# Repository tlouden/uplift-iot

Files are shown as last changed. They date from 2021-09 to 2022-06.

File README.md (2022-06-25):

# UPLIFT-IoT
Connecting an [UPLIFT](https://www.upliftdesk.com/) desk to Home Assistant using an ESP32 with ESP Home for Home Assistant.

## Disclaimer
This is an adversarial interop against a hardware interface. Any changes from the manufacturer could invalidate or even make this dangerous. Validate assumptions on your own system and proceed with caution. 

## Usage
The UART driver for ESP Home should work without modification. Everything else will need to be customized to your setup using the provided examples.

## ESP Home
An ESP32 is used with [ESP Home](https://esphome.io/). The specific board is a esp32doit-devkit-v1.
### esphome/uplift_uart.h
Custom UART driver that interprets the data from the UPLift desk unit.
### uplift-iot.yaml
An example definition for the device in ESPHome. Will need to be customized to be used.

## Home Assistant
Data is consumed by [Home Assistant](https://www.home-assistant.io/).
### homeassistant/automation.yaml 
An example automation which will need to be cusomized to be used.

## PCB / Board
[KiCAD](https://www.kicad.org/) files for a PCB are included for anyone that would like to produce their own. Here is the schematic if you'd like to breadboard it.
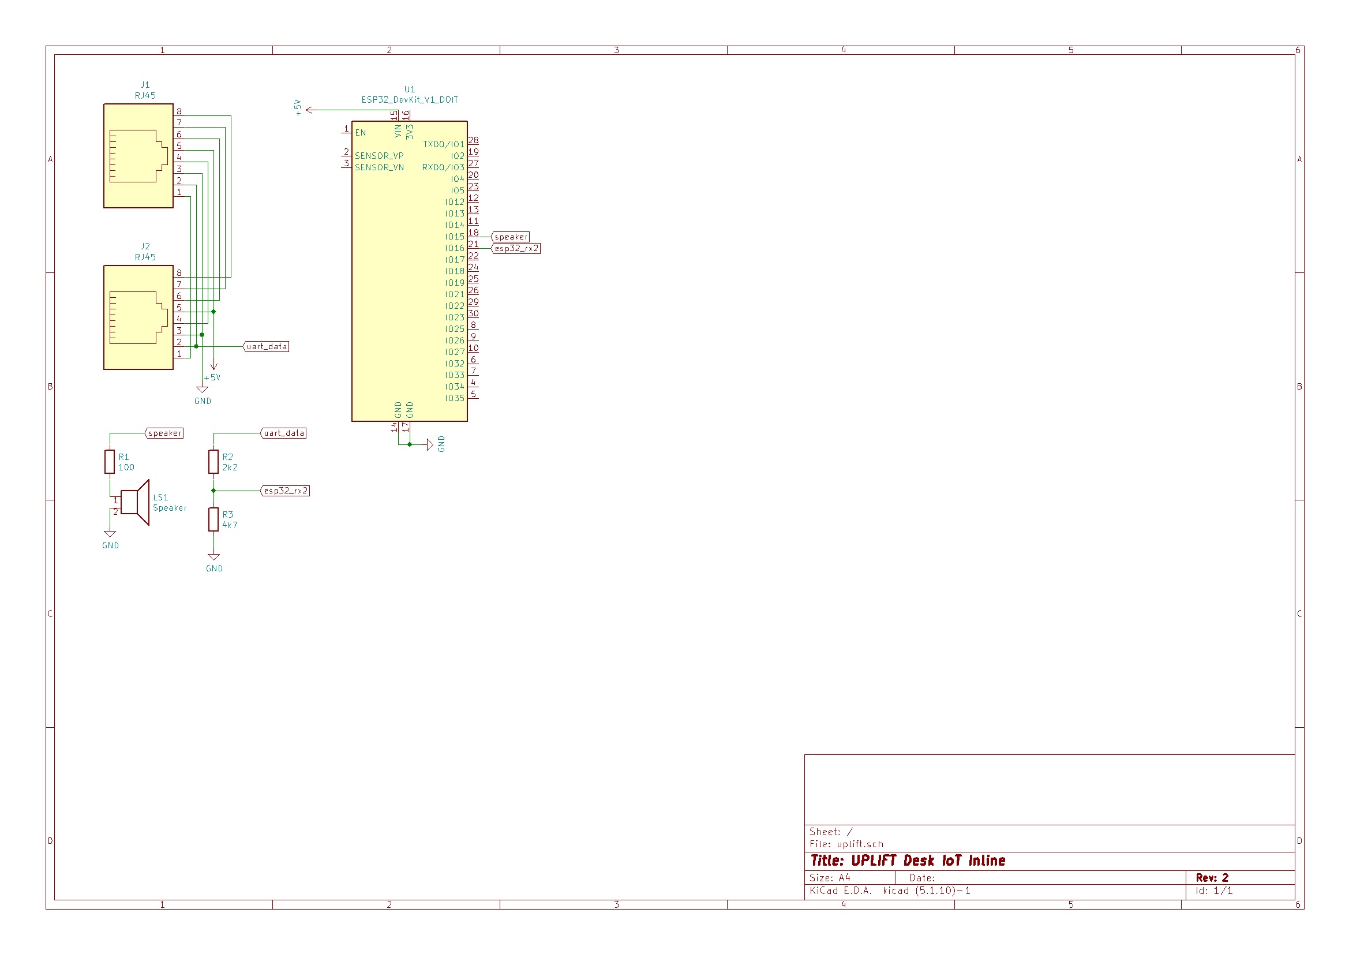
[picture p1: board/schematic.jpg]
schematic


## Enclosure
[OpenSCAD](https://openscad.org/) files for an enclosure are included for 3D printing. The default values are good even if you use a header to connect the ESP to the board. Use M3x4mm screws to attach the PCB. The lid will snap fit. The [BOSL2 library](https://github.com/revarbat/BOSL2) is used and included along with it's license file.

## Details
### UPLIFT Wiring
On My UPLIFT Desk, the keypad communicates with the motor box via an ethernet cable. A logic analyser shows that the second wire has a digital signal at 9600 baud. The third wire is ground, and the fifth is a 5v supply. All the others get pulled low by the keypad when buttons are pressed.
### Signal Analysis
I don't want remote control of the motors, so my analysis is focused exlusively on the serial data on line 2. The data only sends few a short period after the desk height changes, then goes dead. This isn't a problem, but is good to know when doing analysis. Starting with defaults for parity, stop bits, and data length produced the data sequence 1, 1, [0,1], [0-255] repeating. The format is big endian, so the first integer is always 257 and the second is the real data. It is sending the height in tenths of an inch, so 296 is 29.6".
### UART Driver
A simple approach is used for such a simple use case. We look for the expected 1,1 data sequence and then process the next two bytes. It is possible to get out of sequence when the desk is higher than 25.5" so if the first byte is not a 0 or 1, the logic resets to avoid non-sensical readings like 1000". This allows up to 51.1" to be expressed, and my desk only goes up to 50.8".

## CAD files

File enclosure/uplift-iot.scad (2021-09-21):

include <BOSL2/std.scad>
include <BOSL2/rounding.scad>
include <Libraries/calibration.scad>

/* [Rendering Selection] */
Part_To_Render="none"; // [none, full_assembly, bottom, top]

/* [General] */
//width of pcb (x-axis)
pcb_width=52.1;
//length of pcb (y-axis)
pcb_length=58.4;
//distance from inside wall of enclosure to edge of pcb
pcb_right_offset=2.0;
//distance from inside wall of enclosure to edge of pcb
pcb_left_offset=2.0;
//distance from inside wall of enclosure to edge of pcb
pcb_bottom_offset=2.0;
//distance from inside wall of enclosure to edge of pcb
pcb_top_offset=2.0;
//diameter of pcb mounting screws hole
pcb_mounting_screw_hole_diameter=2.5;
//height of pcb standoffs
standoff_height=3.0;
//standoff offset from edge of pcb to center of standoff (assumes symetric holes)
standoff_offset_x=5.0;
//standoff offset from edge of pcb to center of standoff (assumes symetric holes)
standoff_offset_y=3.8;
//distance from bottom of pcb to bottom of rj45 connector hole
rj45_pcb_to_bottom=1.6;
//height of rj45 connector hole (this determines the height of the enclosure)
rj45_height=17.4;
//distance from edge of pcb to edge of rj45 connector hole
rj45_left_offset=10.7;
//width of rj45 connector hole
rj45_width=15.4;
//distance between top of rj45 connector and bottom of lid
rj54_top_to_lid_bottom=5.7;
//width of vent slots
vent_size=2.5;
//margin from edge of lid to edge of venting
vent_free_margin=10.0;

/* [Adjustments] */
min_wall_size=2.0;
snap_fit_size=1.0;

/* [Hidden] */
$debug=false;
$overlap=0.001;
$fn=60;

//Calculated
$slop_tight=$slop*slop_tight_multiple;
$slop_tight_metal_round=$slop*slop_tight_metal_round_multiple;
$slop_tight_metal_square=$slop*slop_tight_metal_square_multiple;
$slop_free=$slop*slop_free_multiple;
enclosure_wall_size=min_wall_size+snap_fit_size+$slop_free;
enclosure_inner_width=pcb_width+pcb_right_offset+pcb_left_offset;
enclosure_width=enclosure_inner_width+2*enclosure_wall_size;
enclosure_inner_length=pcb_length+pcb_bottom_offset+pcb_top_offset;
enclosure_length=enclosure_inner_length+2*enclosure_wall_size;
enclosure_bottom_inner_height=standoff_height+rj45_pcb_to_bottom+rj45_height;
enclosure_bottom_height=min_wall_size+enclosure_bottom_inner_height;
snapfit_cutout_width=snap_fit_size+$slop_free+$overlap;
standoff_diameter=pcb_mounting_screw_hole_diameter+2*min_wall_size;
snapfit_corner_size=4*snap_fit_size+min_wall_size;
vent_x=vent_free_margin;
vent_width=enclosure_width-2*vent_free_margin;
vent_count=floor((enclosure_length-2*vent_free_margin-vent_size)/(2*vent_size))+1;
vent_y_start=enclosure_length/2-(vent_count*2*vent_size-vent_size)/2;

/* DEBUGGING */
if ($debug==true) {
    echo(slop=$slop);
    echo(slop_free=$slop_free);
}

if (Part_To_Render=="full_assembly") render_assembled();
if (Part_To_Render=="bottom") bottom();
if (Part_To_Render=="top") top();


module render_assembled() {
    bottom();
    translate([0, 0, enclosure_bottom_height+2])
    top();
}

module bottom() {
    union() {
        difference() {
            //enclosing
            cuboid([enclosure_width, enclosure_length, enclosure_bottom_height], anchor=FRONT+LEFT+BOTTOM, rounding=min_wall_size, except_edges=[TOP]);
            //inside
            translate([enclosure_wall_size, enclosure_wall_size, min_wall_size])
            cuboid([enclosure_inner_width, enclosure_inner_length, enclosure_bottom_inner_height+$overlap], anchor=FRONT+LEFT+BOTTOM, rounding=min_wall_size, except_edges=[TOP]);
            //rj45 - bottom
            translate([rj45_left_offset+pcb_left_offset+enclosure_wall_size, -$overlap, enclosure_bottom_height-rj45_height])
            cube([rj45_width, enclosure_wall_size+2*$overlap, rj45_height+$overlap]);
            //rj45 - top
            translate([rj45_left_offset+pcb_left_offset+enclosure_wall_size, enclosure_length-enclosure_wall_size-$overlap, enclosure_bottom_height-rj45_height])
            cube([rj45_width, enclosure_wall_size+2*$overlap, rj45_height+$overlap]);
            //snapfit
            translate([enclosure_wall_size+min_wall_size, min_wall_size+$overlap, enclosure_bottom_height-enclosure_wall_size])
            snapfit_cutout();
            translate([enclosure_inner_width-snapfit_cutout_width-min_wall_size, min_wall_size+$overlap, enclosure_bottom_height-enclosure_wall_size])
            snapfit_cutout();
            translate([enclosure_wall_size+min_wall_size, enclosure_inner_length+enclosure_wall_size-$overlap, enclosure_bottom_height-enclosure_wall_size])
            snapfit_cutout();
            translate([enclosure_inner_width-snapfit_cutout_width-min_wall_size, enclosure_inner_length+enclosure_wall_size-$overlap, enclosure_bottom_height-enclosure_wall_size])
            snapfit_cutout();
        }
        //standoffs
        translate([standoff_offset_x+enclosure_wall_size+pcb_left_offset, standoff_offset_y+enclosure_wall_size+pcb_bottom_offset, min_wall_size])
        standoff();
        translate([enclosure_wall_size+enclosure_inner_width-(standoff_offset_x+pcb_left_offset), standoff_offset_y+enclosure_wall_size+pcb_bottom_offset, min_wall_size])
        standoff();
        translate([standoff_offset_x+enclosure_wall_size+pcb_left_offset, enclosure_wall_size+enclosure_inner_length-(standoff_offset_y+pcb_top_offset), min_wall_size])
        standoff();
        translate([enclosure_wall_size+enclosure_inner_width-(standoff_offset_x+pcb_left_offset), enclosure_wall_size+enclosure_inner_length-(standoff_offset_y+pcb_top_offset), min_wall_size])
        standoff();
    }
}

module top() {
    union() {
        //plate
        difference() {
            cuboid([enclosure_width, enclosure_length, min_wall_size], anchor=FRONT+LEFT+BOTTOM, rounding=min_wall_size, except_edges=[BOTTOM, TOP]);
            //ventilation
            for (i=[0:vent_count-1]) {
                translate([vent_x, vent_y_start+i*2*vent_size, -$overlap])
                cuboid([vent_width, vent_size, min_wall_size+2*$overlap], anchor=FRONT+LEFT+BOTTOM, rounding=vent_size/2, except_edges=[BOTTOM, TOP]);
            }
        }
        //snapfit corners
        translate([enclosure_wall_size+$slop, enclosure_wall_size+$slop, -enclosure_wall_size])
        snapfit_corner();
        translate([snapfit_corner_size+enclosure_inner_width-(enclosure_wall_size+$slop), snapfit_corner_size+enclosure_inner_length-(enclosure_wall_size+$slop), -enclosure_wall_size])
        rotate([0, 0, 180])
        snapfit_corner();
        translate([snapfit_corner_size+enclosure_inner_width-(enclosure_wall_size+$slop), enclosure_wall_size+$slop, -enclosure_wall_size])
        rotate([0, 0, 90])
        snapfit_corner(alt=true);
        translate([enclosure_wall_size+$slop, snapfit_corner_size+enclosure_inner_length-(enclosure_wall_size+$slop), -enclosure_wall_size])
        rotate([0, 0, 270])
        snapfit_corner(alt=true);
        //rj45 retentions
        translate([rj45_left_offset+pcb_left_offset+enclosure_wall_size+$slop_free/2, 0, -rj54_top_to_lid_bottom])
        cube([rj45_width-$slop_free, enclosure_wall_size, rj54_top_to_lid_bottom]);
        translate([rj45_left_offset+pcb_left_offset+enclosure_wall_size+$slop_free/2, enclosure_length-enclosure_wall_size, -rj54_top_to_lid_bottom])
        cube([rj45_width-$slop_free, enclosure_wall_size, rj54_top_to_lid_bottom]);
    }
}

module snapfit_corner(alt=false) {
    union() {
        cuboid([snapfit_corner_size, snapfit_corner_size, enclosure_wall_size], anchor=FRONT+LEFT+BOTTOM, rounding=min_wall_size, edges=[FRONT+LEFT]);
        if (alt) {
            translate([-snap_fit_size, min_wall_size+2*snap_fit_size, 0])
            cube([snap_fit_size, snap_fit_size, snap_fit_size]);
        } else {
            translate([min_wall_size+2*snap_fit_size, -snap_fit_size, 0])
            cube([snap_fit_size, snap_fit_size, snap_fit_size]);
        }
    }
}

module snapfit_cutout() {
    cube([4*snap_fit_size, snapfit_cutout_width, snap_fit_size+$slop_free]);
}

module standoff() {
    difference() {
        cylinder(r=standoff_diameter/2, h=standoff_height);
        cylinder(r=pcb_mounting_screw_hole_diameter/2+$slop, h=standoff_height+$overlap);
    }
}

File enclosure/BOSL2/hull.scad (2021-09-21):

//////////////////////////////////////////////////////////////////////
// LibFile: hull.scad
//   Functions to create 2D and 3D convex hulls.
//   To use, add the following line to the beginning of your file:
//   ```
//   include <BOSL2/std.scad>
//   include <BOSL2/hull.scad>
//   ```
//   Derived from Oskar Linde's Hull:
//   - https://github.com/openscad/scad-utils
//////////////////////////////////////////////////////////////////////


// Section: Convex Hulls


// Function: hull()
// Usage:
//   hull(points);
// Description:
//   Takes a list of 2D or 3D points (but not both in the same list) and returns either the list of
//   indexes into `points` that forms the 2D convex hull perimeter path, or the list of faces that
//   form the 3d convex hull surface.  Each face is a list of indexes into `points`.  If the input
//   points are co-linear, the result will be the indexes of the two extrema points.  If the input
//   points are co-planar, the results will be a simple list of vertex indices that will form a planar
//   perimeter.  Otherwise a list of faces will be returned, where each face is a simple list of
//   vertex indices for the perimeter of the face.
// Arguments:
//   points = The set of 2D or 3D points to find the hull of.
function hull(points) =
    assert(is_path(points),"Invalid input to hull")
    len(points[0]) == 2
      ? hull2d_path(points)
      : hull3d_faces(points);


// Module: hull_points()
// Usage:
//   hull_points(points, [fast]);
// Description:
//   If given a list of 2D points, creates a 2D convex hull polygon that encloses all those points.
//   If given a list of 3D points, creates a 3D polyhedron that encloses all the points.  This should
//   handle about 4000 points in slow mode.  If `fast` is set to true, this should be able to handle
//   far more.
// Arguments:
//   points = The list of points to form a hull around.
//   fast = If true, uses a faster cheat that may handle more points, but also may emit warnings that can stop your script if you have "Halt on first warning" enabled.  Default: false
// Example(2D):
//   pts = [[-10,-10], [0,10], [10,10], [12,-10]];
//   hull_points(pts);
// Example:
//   pts = [for (phi = [30:60:150], theta = [0:60:359]) spherical_to_xyz(10, theta, phi)];
//   hull_points(pts);
module hull_points(points, fast=false) {
    if (points) {
        assert(is_list(points[0]));
        if (fast) {
            if (len(points[0]) == 2) {
                hull() polygon(points=points);
            } else {
                extra = len(points)%3;
                faces = concat(
                    [[for(i=[0:1:extra+2])i]],
                    [for(i=[extra+3:3:len(points)-3])[i,i+1,i+2]]
                );
                hull() polyhedron(points=points, faces=faces);
            }
        } else {
            perim = hull(points);
            if (is_num(perim[0])) {
                polygon(points=points, paths=[perim]);
            } else {
                polyhedron(points=points, faces=perim);
            }
        }
    }
}


// Function: hull2d_path()
// Usage:
//   hull2d_path(points)
// Description:
//   Takes a list of arbitrary 2D points, and finds the convex hull polygon to enclose them.
//   Returns a path as a list of indices into `points`.  May return extra points, that are on edges of the hull.
// Example(2D):
//   pts = [[-10,-10], [0,10], [10,10], [12,-10]];
//   path = hull2d_path(pts);
//   move_copies(pts) color("red") sphere(1);
//   polygon(points=pts, paths=[path]);
function hull2d_path(points) =
    assert(is_path(points,2),"Invalid input to hull2d_path")
    len(points) < 2 ? []
  : len(points) == 2 ? [0,1]
  : let(tri=noncollinear_triple(points, error=false))
    tri == [] ? _hull_collinear(points)
  : let(
        remaining = [ for (i = [0:1:len(points)-1]) if (i != tri[0] && i!=tri[1] && i!=tri[2]) i ],
        ccw = triangle_area(points[tri[0]], points[tri[1]], points[tri[2]]) > 0,
        polygon = ccw ? [tri[0],tri[1],tri[2]] : [tri[0],tri[2],tri[1]]
    ) _hull2d_iterative(points, polygon, remaining);



// Adds the remaining points one by one to the convex hull
function _hull2d_iterative(points, polygon, remaining, _i=0) =
    (_i >= len(remaining))? polygon : let (
        // pick a point
        i = remaining[_i],
        // find the segments that are in conflict with the point (point not inside)
        conflicts = _find_conflicting_segments(points, polygon, points[i])
        // no conflicts, skip point and move on
    ) (len(conflicts) == 0)? _hull2d_iterative(points, polygon, remaining, _i+1) : let(
        // find the first conflicting segment and the first not conflicting
        // conflict will be sorted, if not wrapping around, do it the easy way
        polygon = _remove_conflicts_and_insert_point(polygon, conflicts, i)
    ) _hull2d_iterative(points, polygon, remaining, _i+1);


function _hull_collinear(points) =
    let(
        a = points[0],
        n = points[1] - a,
        points1d = [ for(p = points) (p-a)*n ],
        min_i = min_index(points1d),
        max_i = max_index(points1d)
    ) [min_i, max_i];


function _find_conflicting_segments(points, polygon, point) = [
    for (i = [0:1:len(polygon)-1]) let(
        j = (i+1) % len(polygon),
        p1 = points[polygon[i]],
        p2 = points[polygon[j]],
        area = triangle_area(p1, p2, point)
    ) if (area < 0) i
];


// remove the conflicting segments from the polygon
function _remove_conflicts_and_insert_point(polygon, conflicts, point) = 
    (conflicts[0] == 0)? let(
        nonconflicting = [ for(i = [0:1:len(polygon)-1]) if (!in_list(i, conflicts)) i ],
        new_indices = concat(nonconflicting, (nonconflicting[len(nonconflicting)-1]+1) % len(polygon)),
        polygon = concat([ for (i = new_indices) polygon[i] ], point)
    ) polygon : let(
        before_conflicts = [ for(i = [0:1:min(conflicts)]) polygon[i] ],
        after_conflicts  = (max(conflicts) >= (len(polygon)-1))? [] : [ for(i = [max(conflicts)+1:1:len(polygon)-1]) polygon[i] ],
        polygon = concat(before_conflicts, point, after_conflicts)
    ) polygon;



// Function: hull3d_faces()
// Usage:
//   hull3d_faces(points)
// Description:
//   Takes a list of arbitrary 3D points, and finds the convex hull polyhedron to enclose
//   them.  Returns a list of triangular faces, where each face is a list of indexes into the given `points`
//   list.  The output will be valid for use with the polyhedron command, but may include vertices that are in the interior of a face of the hull, so it is not
//   necessarily the minimal representation of the hull.  
//   If all points passed to it are coplanar, then the return is the list of indices of points
//   forming the convex hull polygon.
// Example(3D):
//   pts = [[-20,-20,0], [20,-20,0], [0,20,5], [0,0,20]];
//   faces = hull3d_faces(pts);
//   move_copies(pts) color("red") sphere(1);
//   %polyhedron(points=pts, faces=faces);
function hull3d_faces(points) =
    assert(is_path(points,3),"Invalid input to hull3d_faces")
    len(points) < 3 ? list_range(len(points))
  : let ( // start with a single non-collinear triangle
          tri = noncollinear_triple(points, error=false)
        )
    tri==[] ? _hull_collinear(points)
  : let(
        a = tri[0],
        b = tri[1],
        c = tri[2],
        plane = plane3pt_indexed(points, a, b, c),
        d = _find_first_noncoplanar(plane, points, 3)
    )
    d == len(points)
  ? /* all coplanar*/
    let (
        pts2d = [ for (p = points) project_plane(p, points[a], points[b], points[c]) ],
        hull2d = hull2d_path(pts2d)
    ) hull2d
  : let(
        remaining = [for (i = [0:1:len(points)-1]) if (i!=a && i!=b && i!=c && i!=d) i],
        // Build an initial tetrahedron.
        // Swap b, c if d is in front of triangle t.
        ifop = in_front_of_plane(plane, points[d]),
        bc = ifop? [c,b] : [b,c],
        b = bc[0],
        c = bc[1],
        triangles = [
            [a,b,c],
            [d,b,a],
            [c,d,a],
            [b,d,c]
        ],
        // calculate the plane equations
        planes = [ for (t = triangles) plane3pt_indexed(points, t[0], t[1], t[2]) ]
    ) _hull3d_iterative(points, triangles, planes, remaining);
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

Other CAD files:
enclosure/BOSL2/constants.scad
enclosure/BOSL2/nema_steppers.scad
enclosure/BOSL2/affine.scad
enclosure/BOSL2/arrays.scad
enclosure/BOSL2/attachments.scad
enclosure/BOSL2/beziers.scad
enclosure/BOSL2/bosl1compat.scad
enclosure/BOSL2/bottlecaps.scad
enclosure/BOSL2/common.scad
enclosure/BOSL2/coords.scad
enclosure/BOSL2/cubetruss.scad
enclosure/BOSL2/debug.scad
enclosure/BOSL2/distributors.scad
enclosure/BOSL2/edges.scad
enclosure/BOSL2/geometry.scad
enclosure/BOSL2/hingesnaps.scad
enclosure/BOSL2/involute_gears.scad
enclosure/BOSL2/joiners.scad
enclosure/BOSL2/knurling.scad
enclosure/BOSL2/linear_bearings.scad
enclosure/BOSL2/masks.scad
enclosure/BOSL2/math.scad
enclosure/BOSL2/metric_screws.scad
enclosure/BOSL2/mutators.scad
enclosure/BOSL2/partitions.scad
enclosure/BOSL2/paths.scad
enclosure/BOSL2/phillips_drive.scad
enclosure/BOSL2/polyhedra.scad
enclosure/BOSL2/primitives.scad
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

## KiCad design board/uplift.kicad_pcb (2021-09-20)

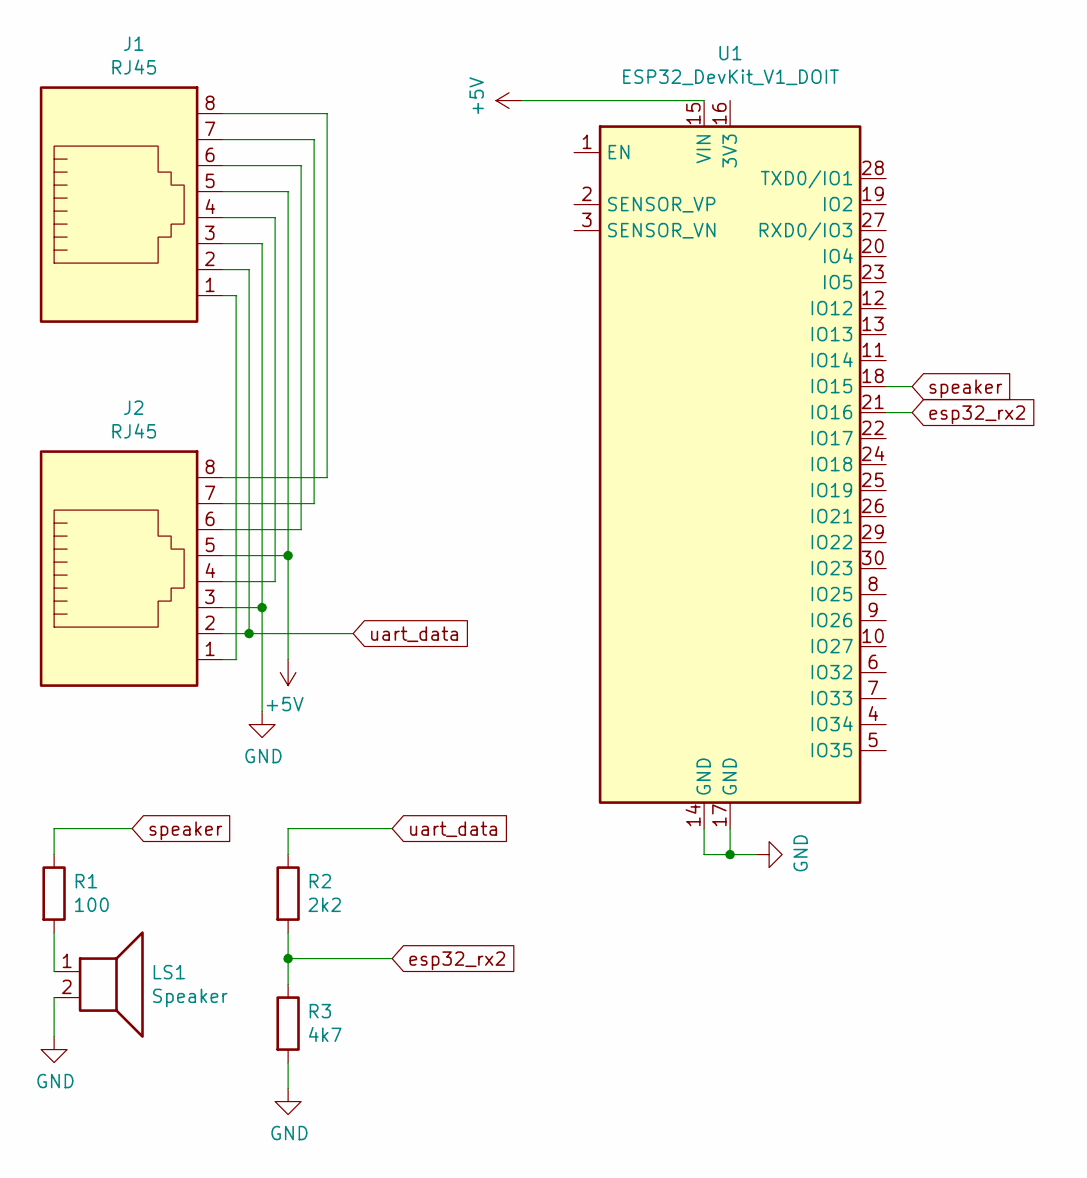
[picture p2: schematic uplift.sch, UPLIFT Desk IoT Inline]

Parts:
J1, J2: RJ45; RJ45_Amphenol_54602-x08_Horizontal
LS1: Speaker; MagneticBuzzer_ProSignal_ABT-410-RC
R1: 100; R_Axial_DIN0207_L6.3mm_D2.5mm_P10.16mm_Horizontal
R2: 2k2; R_Axial_DIN0207_L6.3mm_D2.5mm_P10.16mm_Horizontal
R3: 4k7; R_Axial_DIN0207_L6.3mm_D2.5mm_P10.16mm_Horizontal
U1: ESP32_DevKit_V1_DOIT; esp32_devkit_v1_doit

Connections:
+5V: J1.5, J2.5, U1.15 (VIN)
GND: J1.3, J2.3, LS1.2, R3.2, U1.14 (GND), U1.17 (GND)
unnamed: J1.1, J2.1
unnamed: J1.4, J2.4
unnamed: J1.6, J2.6
unnamed: J1.7, J2.7
unnamed: J1.8, J2.8
unnamed: LS1.1, R1.2
esp32_rx2: R2.2, R3.1, U1.21 (IO16)
speaker: R1.1, U1.18 (IO15)
uart_data: J1.2, J2.2, R2.1

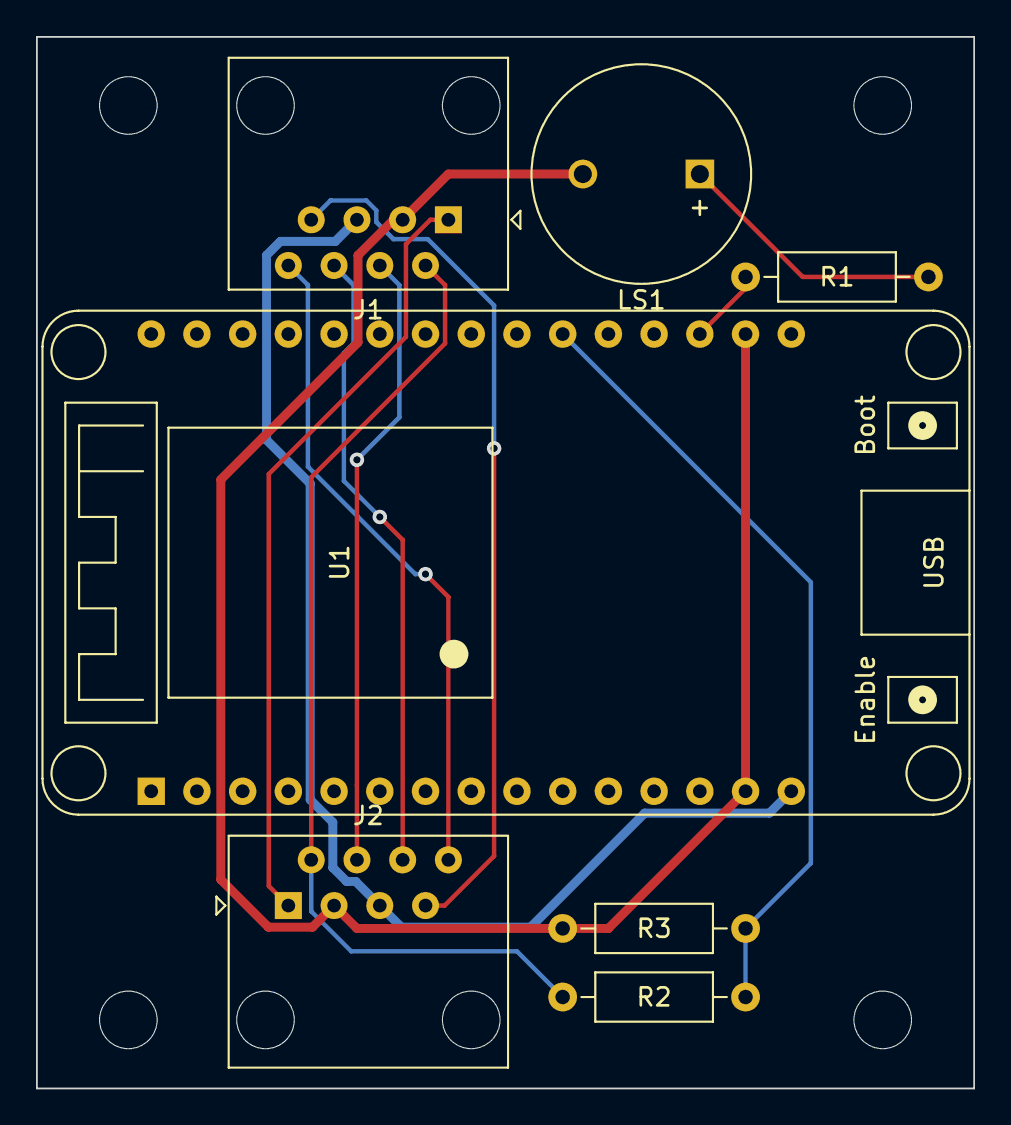
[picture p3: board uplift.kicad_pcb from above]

Board: 2 copper layers, 52.1 x 58.4 mm, 7 parts (0 on the bottom side), 11 nets.

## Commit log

2021-09-20 combine c++ and kicad exclusions
2021-09-20 board, esphome, and home assistant files
    [uplift.kicad_pcb, uplift.sch]
2021-09-21 add enclosure files
    [affine.scad, arrays.scad, attachments.scad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]
